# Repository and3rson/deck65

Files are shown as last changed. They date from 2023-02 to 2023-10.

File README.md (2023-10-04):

# Deck65

Homebrew 6502-based single-board computer with WiFi, built-in mechanical keyboard, uSD card adapter, I2C/SPI, EEPROM, & RTC.

Deck65 SBC
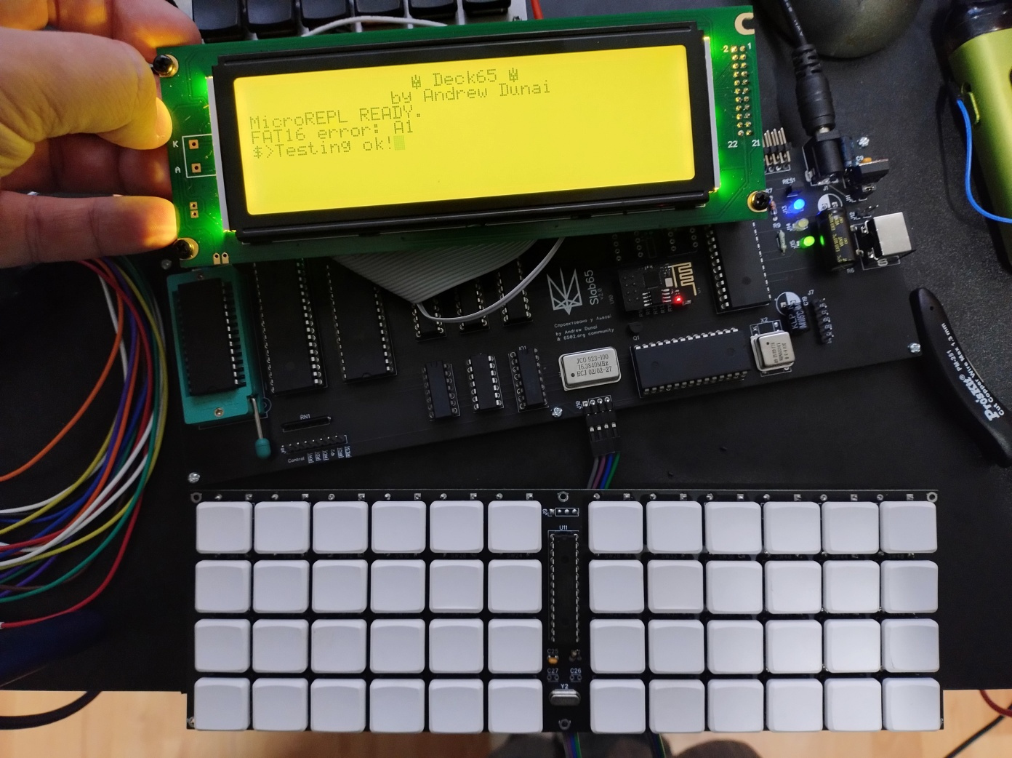
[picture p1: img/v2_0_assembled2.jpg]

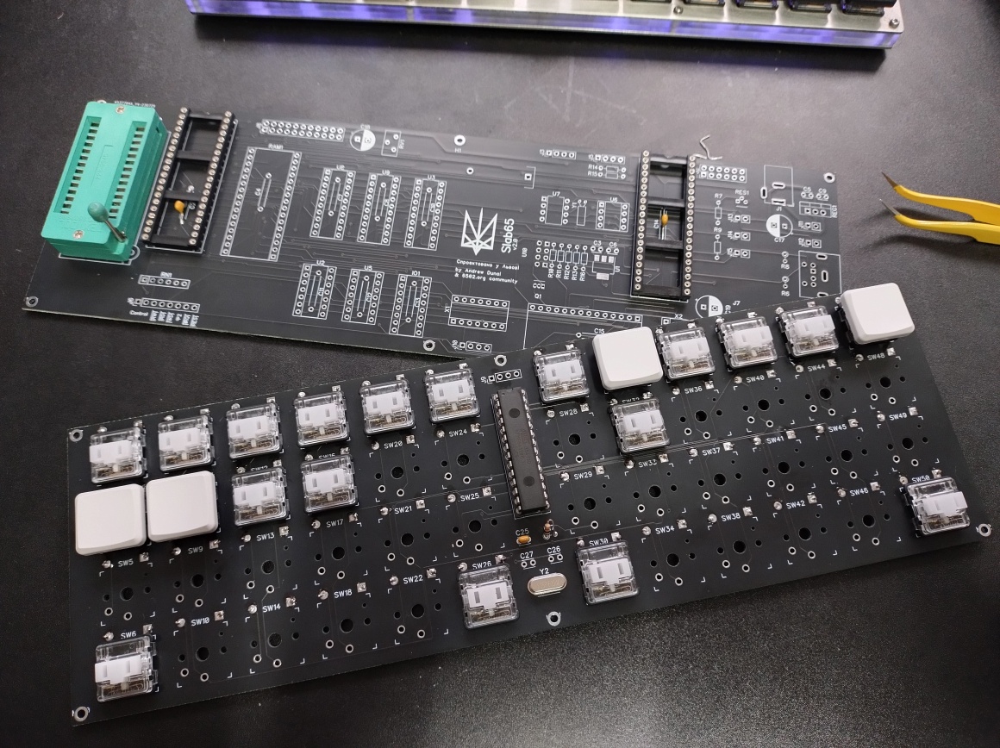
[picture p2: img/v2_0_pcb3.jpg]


- New discussion: <http://forum.6502.org/viewtopic.php?f=6&t=7682>
- Original thread (old SBC version): <http://forum.6502.org/viewtopic.php?f=12&t=7501>

Pull with `git pull --recurse-submodules`.

# Memory map

```
+--------------+-------+------------------+------+------------------------------------------+
| RANGE        | TYPE  | ADDR             | SIZE | Notes                                    |
+--------------+-------+------------------+------+------------------------------------------+
| $0000..$0FFF | RAM   | 0000------------ | 32 K | /EN = A15                                |
| $1000..$1FFF |       | 0001------------ |      | $0000..$1000 - zeropage & video buffer   |
| $2000..$2FFF |       | 0010------------ |      | $1000..$7FFF - programs from SD Card     |
| $3000..$3FFF |       | 0011------------ |      |                                          |
| $4000..$4FFF |       | 0100------------ |      |                                          |
| $5000..$5FFF |       | 0101------------ |      |                                          |
| $6000..$6FFF |       | 0110------------ |      |                                          |
| $7000..$7FFF |       | 0111------------ |      |                                          |
+--------------+-------+------------------+------+------------------------------------------+
| $8000..$8FFF | LOROM | 1000------------ | 16 K | /EN = NAND(A15, NAND(A14))               |
| $9000..$9FFF |       | 1001------------ |      | Contains OS ("MicroREPL")                |
| $A000..$AFFF |       | 1010------------ |      |                                          |
| $B000..$BFFF |       | 1011------------ |      |                                          |
+--------------+-------+------------------+------+------------------------------------------+
| $C000..$CFFF | N/C   | 1100------------ | 4 K  | Unused, may add extra '138 with /GA=/A13 |
+--------------+-------+------------------+------+------------------------------------------+
| $D000..$DFFF | I/O   | 1101------------ | 4 K  | G = A12, /GA = A13, /GB = NAND(A15, A14) |
|              |       | 1101-000-------- | 256B | $D000..$D0FF - RAM banking register      |
|              |       | 1101-001-------- | 256B | $D100..$D1FF - 6522 VIA                  |
|              |       | 1101-010-------- | 256B | $D200..$D2FF - 6551 ACIA                 |
|              |       | 1101-011-------- | 256B | $D300..$D3FF - T6963C LCD (240x64)       |
+--------------+-------+------------------+------+------------------------------------------+
| $E000..$EFFF | HIROM | 1110------------ | 8 K  | /EN = NAND(/NAND(A15, A14), A13)         |
| $F000..$FFFF |       | 1111------------ |      | Contains Kernel ("Kore")                 |
+--------------+-------+------------------+------+------------------------------------------+

LOROM (10xx) || HIROM (111x):
/EN = A15 && (/A14 || (A14 && A13))
/EN = NAND(A15, /A14 || /NAND(A14, A13))
/EN = NAND(A15, NAND(A14, NAND(A14, A13)))
```

# Features

- W65C02, 512 KB RAM (32KB visible to CPU, banked into 4 x 8 KB segments)
- 240x64 LCD display (T6963C)
- Built-in [mechanical PS/2 keyboard](./keyboard), powered by ATmega328P
- Internet! Works through ESP-01
- VIA W65C22<ins>N</ins>(6TPG-14)

  Provides:
  - SPI (used for Micro SD Card adapter)
  - I2C (used for RTC & EEPROM)
  - PS/2 host (used for built-in or external keyboard)
- ACIA W65C51<ins>N</ins>(6TPG-14)n

  Provides:
  - Communication with ESP-01
  - Communication with external devices through pin header
  > Note: I'm using NMOS-compatible versions of VIA & ACIA (<ins>N</ins> suffix) with open-drain /IRQ line.<br />
  > See http://archive.6502.org/datasheets/wdc_w65c22_sep_13_2010.pdf (page 25) for more details.
- Address decoder & underclocking - [ATF16V8B-15PU](./gal)
  > Main crystal is 16 MHz, and the CPU runs at either 8 MHz or 2 MHz.<br />
  > Reason for this is that T6963C LCD can only operate on up to 2.75 MHz.<br />
  > So when CPU needs to acccess the LCD, ATF16V8 divides clock speed by 4, bringing it down to 2 MHz.<br />
  > This is done by implementing a 2-bit counter using registered outputs.
- Memory banking: 74LS670
  > Entire RAM (first 32 KB) is divided into 4 x 8 KB segments.<br />
  > Each segment can use one of its own 16 banks.<br />
  > This allows to selectively bank parts of RAM in and out.<br />
  > Using a machine-tooled socket actually allows to connect JCO-8 or JCO-14 oscillators.
- Traco Power TSR 1-2450 (drop-in replacement for 7805)
  > It runs much cooler than L7805 since it's a switching regulator.<br />
  > I use them a lot, although they are not as cheap as 7805.

V2.0 schematic:
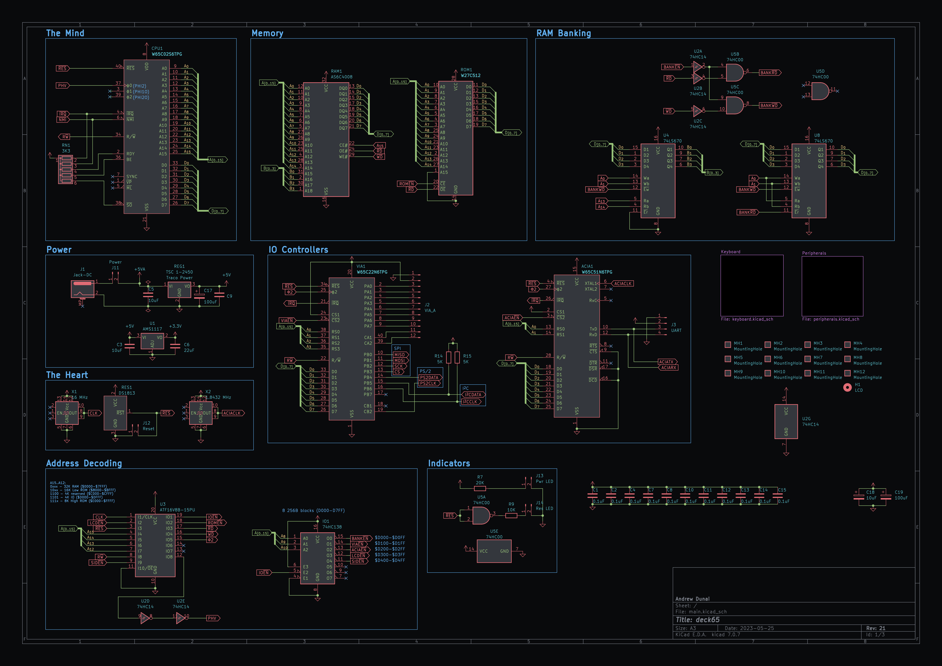
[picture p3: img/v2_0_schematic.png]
65c02s SBC PCB


# ROM

Kernel code currently provides the following features:
- Simple REPL shell to monitor memory & run programs
- 128x64 LCD (through VIA)
- PS/2 keyboard (through VIA)
- Micro SD Card in SPI mode (through VIA)
- I2C & SPI support
- Basic FAT16 support - listing root folder, loading/executing programs

# Resources

- [Kicad files](./kicad) - <https://www.kicad.org/>
- [DipTrace PCBs](./diptrace) - <https://diptrace.com/>
- [Circuits](./circuits) (created with [Digital](https://github.com/hneemann/Digital))
- [ROM sources](./rom) (written in 6502 Assembly, requires [cc65](https://cc65.github.io/) compiler)
- [SD Card programs](./sdcard) (written in 6502 C, requires [cc65](https://cc65.github.io/) compiler)
- [Keyboard firmware](./keyboard) (written in C)
- [GAL stuff](./gal) (hexadecimal 7-segment decoder, address decoder, etc using GAL16V8/GAL20V8, includes `galasm` as submodule)
- [Composite video test](./compvid) using ATtiny45 (requires [avra](https://github.com/Ro5bert/avra))

# So what can you do with it?

Playing snake, for example:

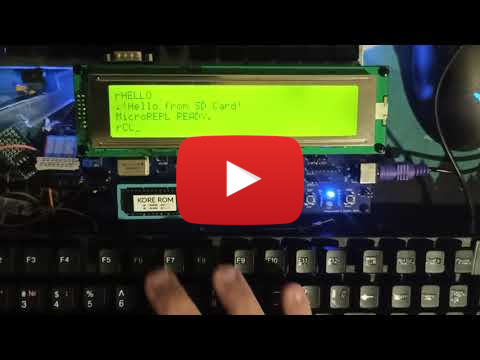
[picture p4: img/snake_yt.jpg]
Snake on 65C02 SBC (https://www.youtube.com/watch?v=boeysL1Isg4)


# Credits & references
- [6502.org community](forum.6502.org/) - Limitless help & support
- https://www.masswerk.at/6502/6502_instruction_set.html
- https://github.com/4x1md/kicad_libraries - Mini-DIN-6 symbol & footprint
- http://39k.ca/reading-files-from-fat16/
- https://laughtonelectronics.com/Arcana/KimKlone/Kimklone_opcode_mapping.html - cool illegal NOPs
- https://octopart.componentsearchengine.com/part.php?partID=570717&ref=octopart - Aries 28-526-10 footprint
- https://github.com/daprice/keyswitches.pretty - MX switches
- https://components101.com/sites/default/files/component_datasheet/Micro-SD-Card-Module-Datasheet.pdf - MicroSD card module datasheet & dimensions
- http://static.cactus.io/docs/sensors/temp-humidity/mcp9808/25095A.pdf - MCP9808 I2C temperature sensor
- https://ww1.microchip.com/downloads/aemDocuments/documents/MPD/ProductDocuments/DataSheets/24AA512-24LC512-24FC512-512K-Bit-I2C-Serial-EEPROM-20001754Q.pdf

# Links
- 6502 Primer: http://wilsonminesco.com/6502primer/
- Address Selector: https://circuitverse.org/simulator/embed/6502-address-selector
- Read-Write Selector: https://circuitverse.org/simulator/embed/6502-read-write-selector
- SID (HVSC) format: https://gist.github.com/cbmeeks/2b107f0a8d36fc461ebb056e94b2f4d6

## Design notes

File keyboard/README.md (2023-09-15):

# Keyboard

*- 48 keys is all you need.*

Firmware for ATmega328P-powered mechanical PS/2 keyboard.

Inspired by [QMK firmware](https://qmk.fm/).

## Features

- Key press delay & repeat
- Switch debouncing
- Basic & extended make/break scancodes
- Multi-layer support (extending total number of possible unique keys to thousands)

  I use two layer keys: "alpha" & "beta".
  - Main layer contains QWERTY layout and most used function keys (Ctrl/Alt/Shift/Meta, Return, Backspace, Escape, etc)
  - "Alpha" activates navigation layer (I/J/K/L = Up/Left/Down/Right, H/N = Home/End, U/O = PageUp/PageDown, etc)
  - "Beta" activates digits and F-keys.

## Keyboard layout

### Main layer
```
┏━━━━━┳━━━━━┯━━━━━┯━━━━━┯━━━━━┯━━━━━┳━━━━━┯━━━━━┯━━━━━┯━━━━━┯━━━━━┳━━━━━┓
┃ TAB ┃  Q  │  W  │  E  │  R  │  T  ┃  Y  │  U  │  I  │  O  │  P  ┃BKSPC┃
┣━━━━━╉─────┼─────┼─────┼─────┼─────╂─────┼─────┼─────┼─────┼─────╊━━━━━┫
┃  𝛼  ┃  A  │  S  │  D  │  F  │  G  ┃  H  │  J  │  K  │  L  │  ;  ┃ RET ┃
┣━━━━━╉─────┼─────┼─────┼─────┼─────╂─────┼─────┼─────┼─────┼─────╊━━━━━┫
┃SHIFT┃  Z  │  X  │  C  │  V  │  B  ┃  N  │  M  │  ,  │  .  │  /  ┃ CTRL┃
┣━━━━━╉─────┼─────┼─────┼─────┼─────╂─────┼─────┼─────┼─────┼─────╊━━━━━┫
┃ CTRL┃ ESC │     │     │     │SPACE┃SPACE│  𝛽  │     │     │     ┃     ┃
┗━━━━━┻━━━━━┷━━━━━┷━━━━━┷━━━━━┷━━━━━┻━━━━━┷━━━━━┷━━━━━┷━━━━━┷━━━━━┻━━━━━┛
```

### Alpha layer
```
┏━━━━━┳━━━━━┯━━━━━┯━━━━━┯━━━━━┯━━━━━┳━━━━━┯━━━━━┯━━━━━┯━━━━━┯━━━━━┳━━━━━┓
┃     ┃     │     │     │     │     ┃  -  │PAGE↑│  ↑  │PAGE↓│     ┃ DEL ┃
┣━━━━━╉─────┼─────┼─────┼─────┼─────╂─────┼─────┼─────┼─────┼─────╊━━━━━┫
┃     ┃     │     │     │     │     ┃ HOME│  ←  │  ↓  │  →  │  `  ┃     ┃
┣━━━━━╉─────┼─────┼─────┼─────┼─────╂─────┼─────┼─────┼─────┼─────╊━━━━━┫
┃     ┃     │     │     │     │     ┃ END │  =  │  [  │  ]  │     ┃     ┃
┣━━━━━╉─────┼─────┼─────┼─────┼─────╂─────┼─────┼─────┼─────┼─────╊━━━━━┫
┃     ┃     │     │     │     │     ┃     │     │     │     │     ┃     ┃
┗━━━━━┻━━━━━┷━━━━━┷━━━━━┷━━━━━┷━━━━━┻━━━━━┷━━━━━┷━━━━━┷━━━━━┷━━━━━┻━━━━━┛
```

### Beta layer
```
┏━━━━━┳━━━━━┯━━━━━┯━━━━━┯━━━━━┯━━━━━┳━━━━━┯━━━━━┯━━━━━┯━━━━━┯━━━━━┳━━━━━┓
┃     ┃  1  │  2  │  3  │  4  │  5  ┃  6  │  7  │  8  │  9  │  0  ┃ F12 ┃
┣━━━━━╉─────┼─────┼─────┼─────┼─────╂─────┼─────┼─────┼─────┼─────╊━━━━━┫
┃     ┃  F1 │  F2 │  F3 │  F4 │  F5 ┃  F6 │  F7 │  F8 │  F9 │ F10 ┃ F11 ┃
┣━━━━━╉─────┼─────┼─────┼─────┼─────╂─────┼─────┼─────┼─────┼─────╊━━━━━┫
┃     ┃     │     │     │     │     ┃     │     │     │     │     ┃     ┃
┣━━━━━╉─────┼─────┼─────┼─────┼─────╂─────┼─────┼─────┼─────┼─────╊━━━━━┫
┃     ┃     │     │     │     │     ┃     │     │     │     │     ┃     ┃
┗━━━━━┻━━━━━┷━━━━━┷━━━━━┷━━━━━┷━━━━━┻━━━━━┷━━━━━┷━━━━━┷━━━━━┷━━━━━┻━━━━━┛
```

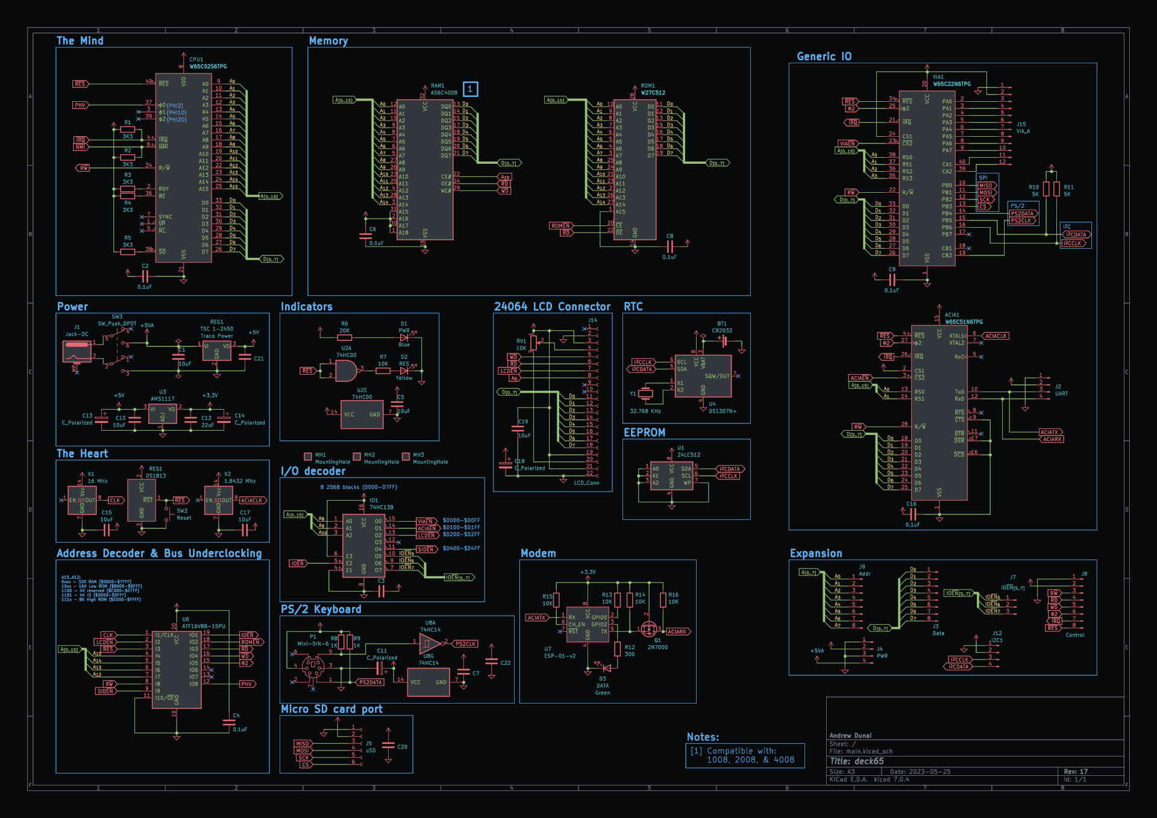
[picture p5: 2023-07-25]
img/v17_schematic.jpg

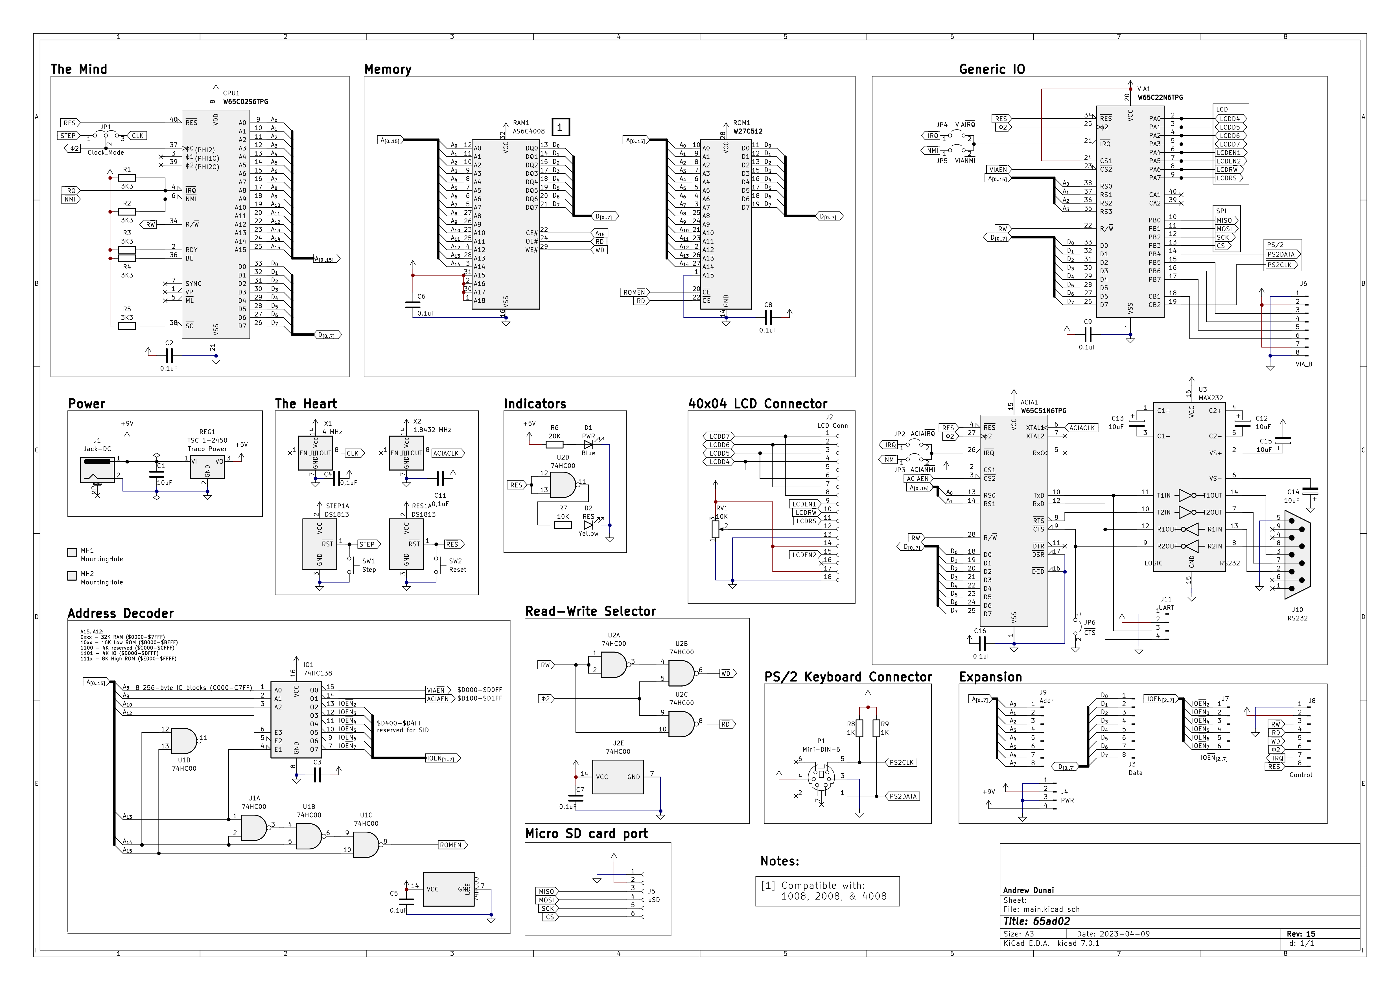
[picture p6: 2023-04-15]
img/v15_schematic.png

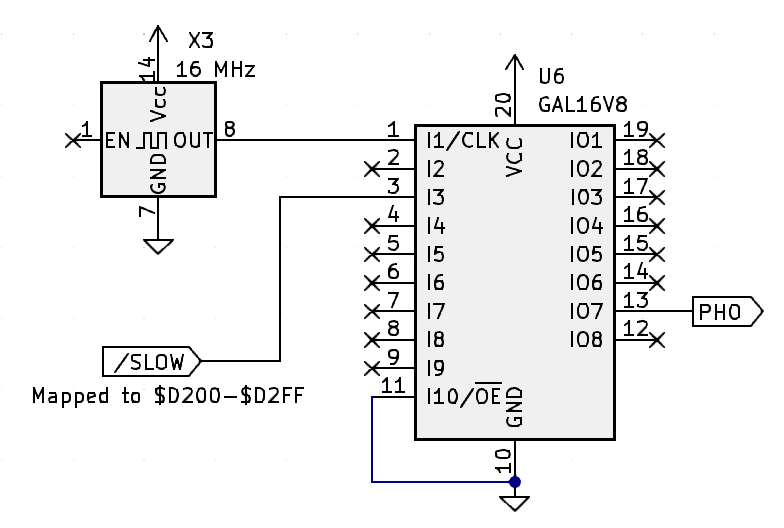
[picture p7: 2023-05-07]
img/slowbus_schematic.png

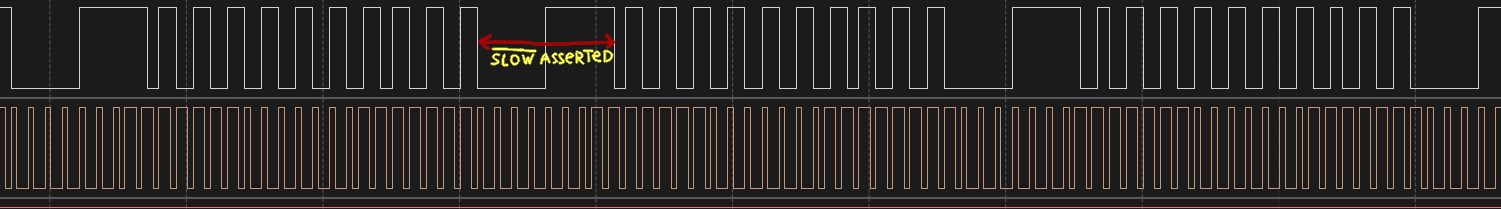
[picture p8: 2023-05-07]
img/slowbus_real.png

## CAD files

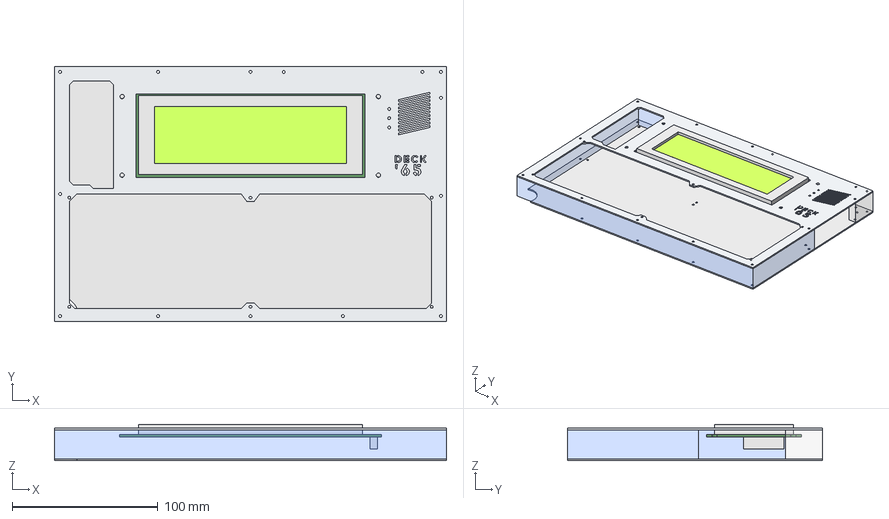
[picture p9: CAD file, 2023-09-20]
case/main_case.FCStd
269.2 x 175.3 x 25.0 mm
Тіло
Тіло001
Тіло002
Тіло003
PCBBody
ConnBody
Matrix
Display

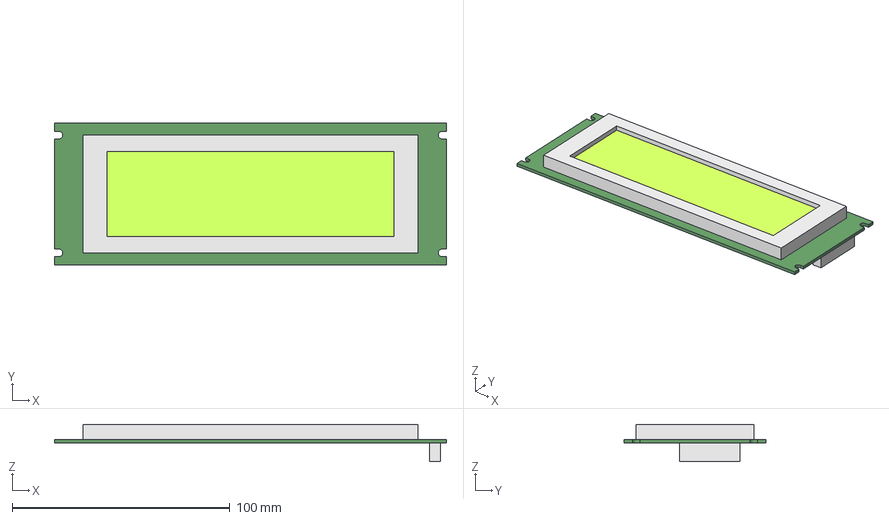
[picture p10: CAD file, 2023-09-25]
case/lcd.FCStd
180.0 x 65.0 x 17.1 mm
PCBBody
ConnBody
Matrix
Display

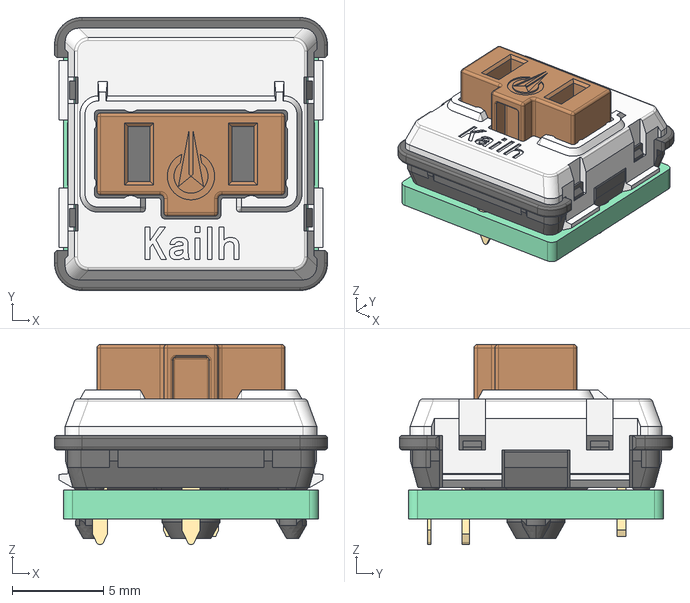
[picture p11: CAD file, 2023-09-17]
kicad/3dmodels/Kailh Choc Low Profile Switch.step
15.0 x 15.0 x 11.0 mm

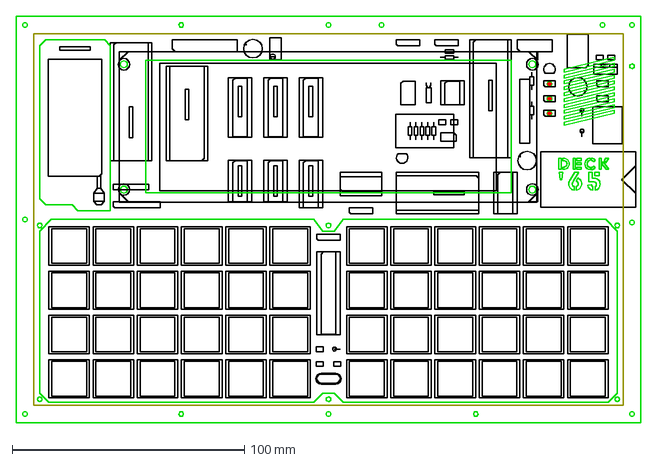
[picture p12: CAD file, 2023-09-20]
case/top.dxf
269.2 x 175.3 mm

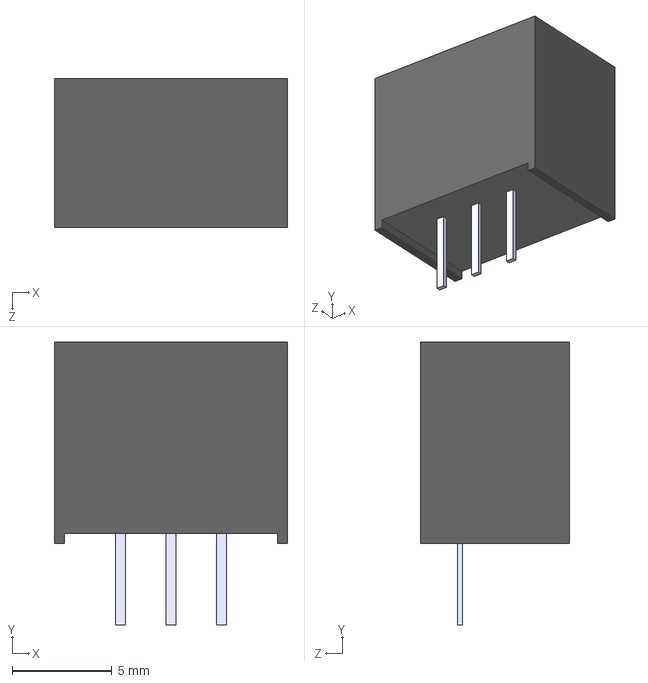
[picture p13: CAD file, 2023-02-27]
kicad/3dmodels/TSR_1-2450.stp
11.7 x 14.2 x 7.50 mm

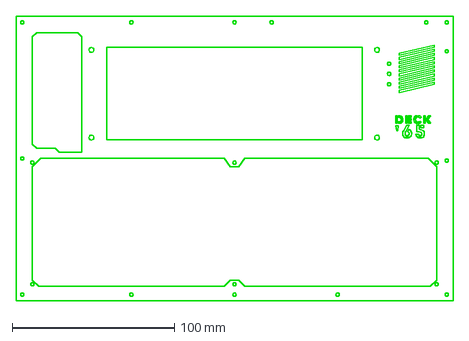
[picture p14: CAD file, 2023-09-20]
case/top_print.dxf
269.2 x 175.3 mm

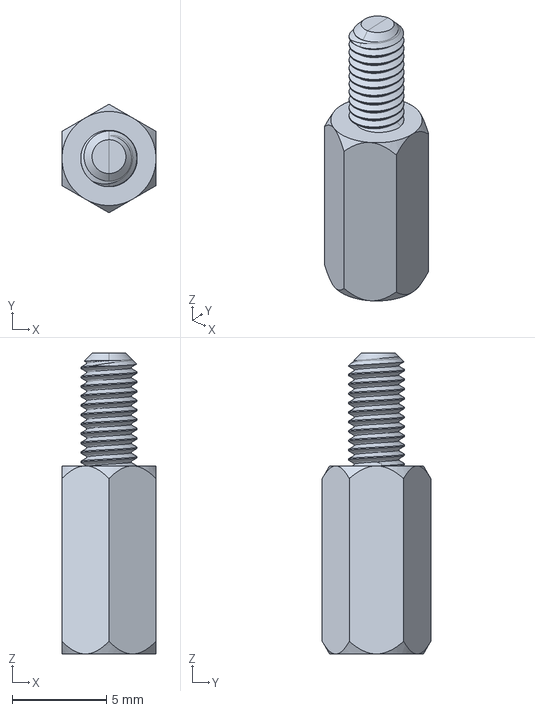
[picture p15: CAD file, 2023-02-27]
kicad/3dmodels/Hex_Spacer_MF_M3_L10mm.stp
5.00 x 5.77 x 16.0 mm

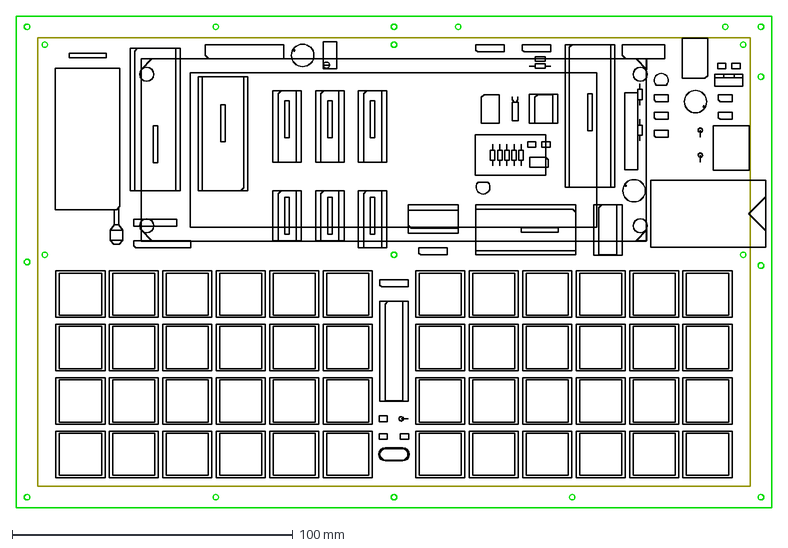
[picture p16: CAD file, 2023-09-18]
case/bottom.dxf
269.2 x 175.3 mm

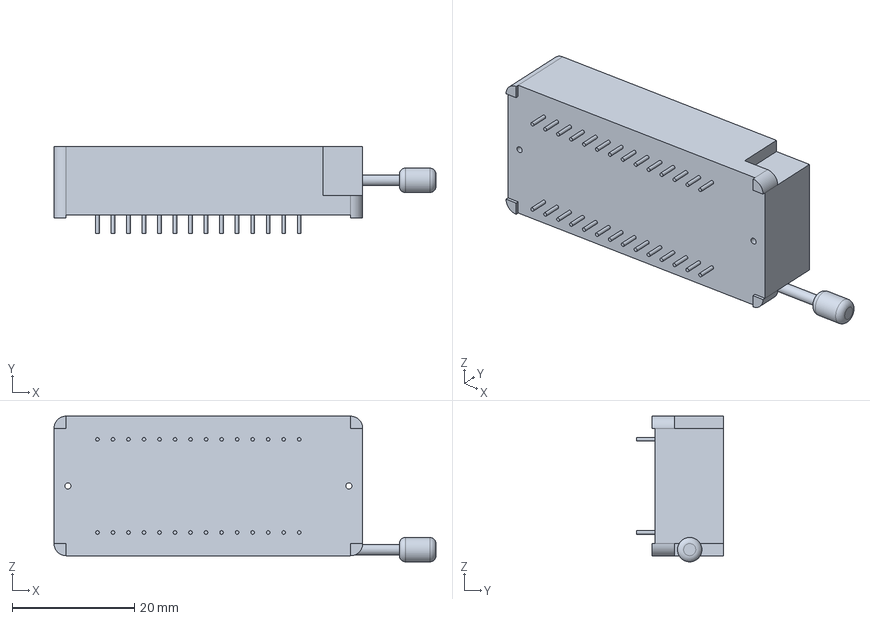
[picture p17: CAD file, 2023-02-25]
kicad/3dmodels/28ZIF_PlaceHolderRevB.stp
62.5 x 14.2 x 23.9 mm

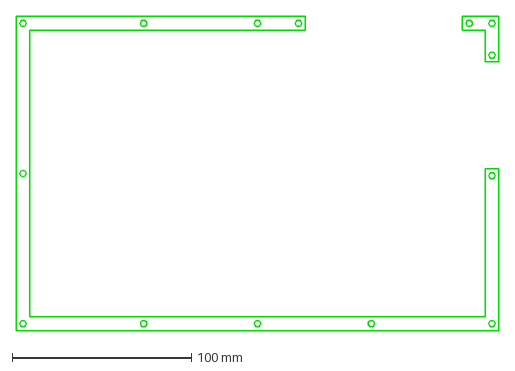
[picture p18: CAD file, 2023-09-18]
case/middle.dxf
269.2 x 175.3 mm

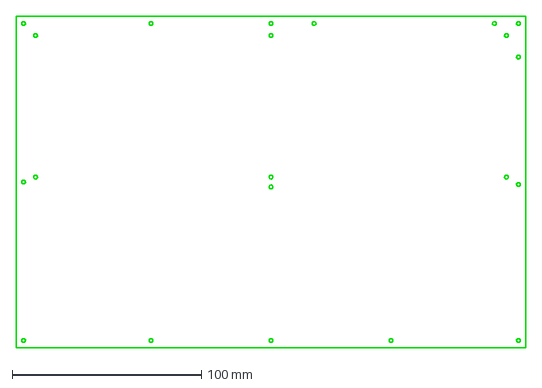
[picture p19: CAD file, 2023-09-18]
case/bottom_print.dxf
269.2 x 175.3 mm

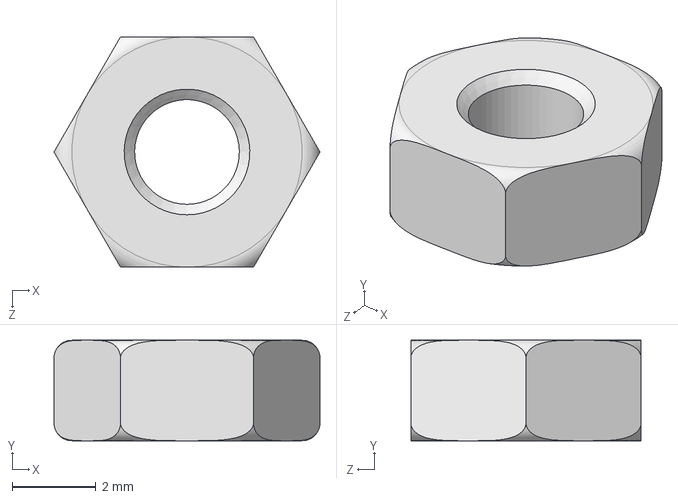
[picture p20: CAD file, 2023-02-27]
kicad/3dmodels/DIN_934_Nut_M3.stp
6.35 x 2.40 x 5.50 mm

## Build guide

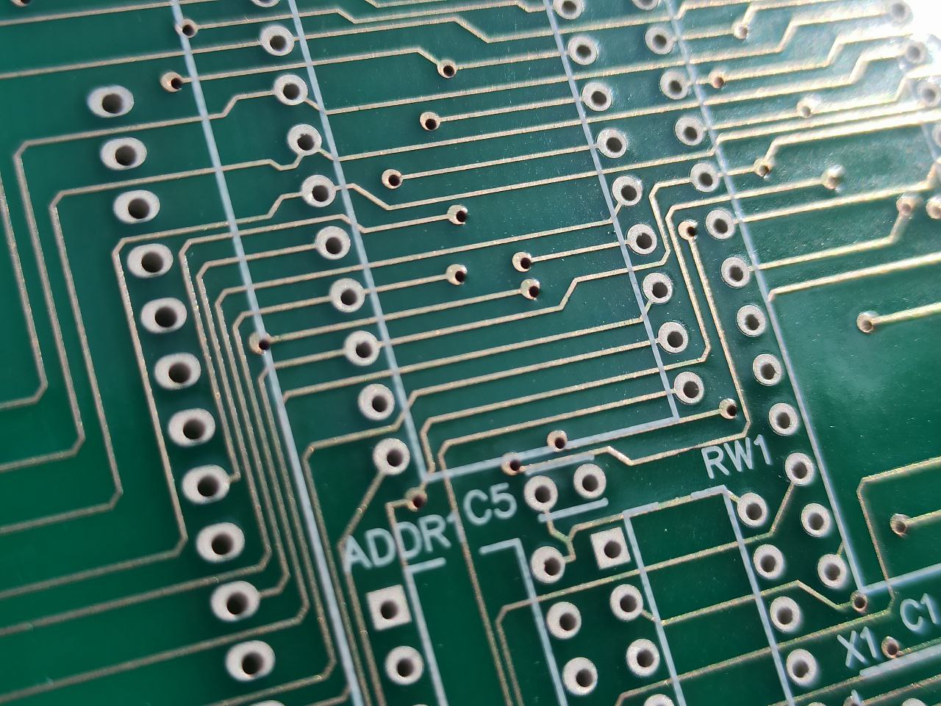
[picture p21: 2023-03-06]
img/v09_printed2.jpg

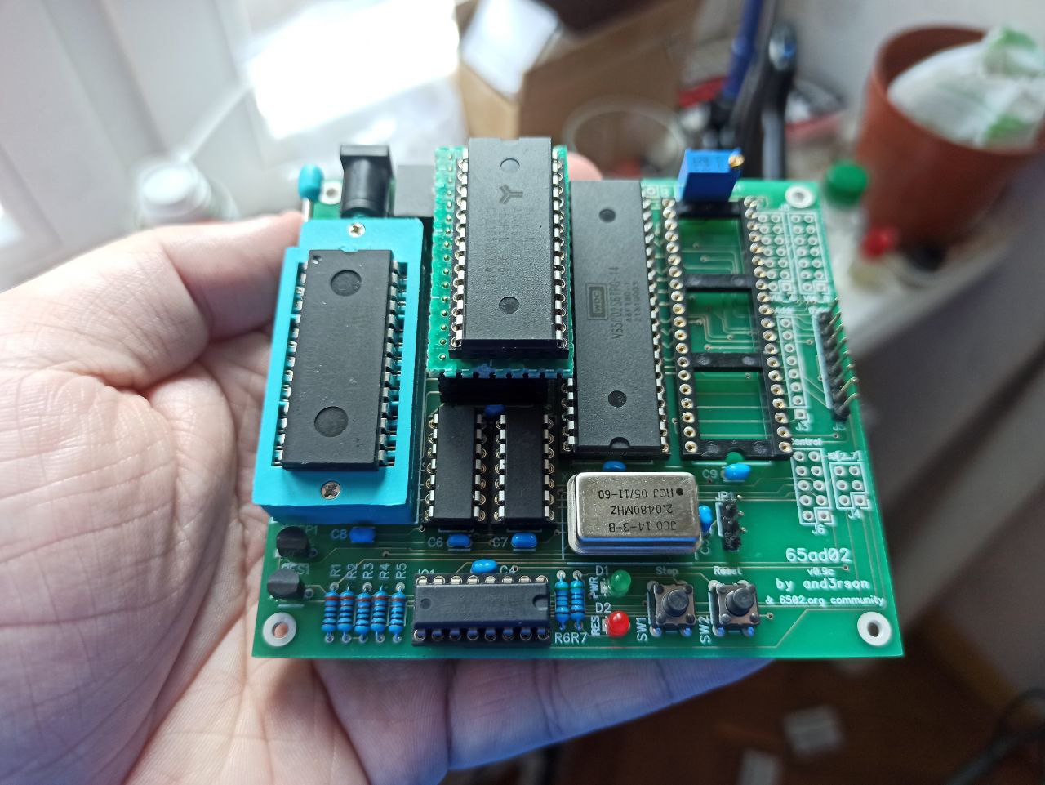
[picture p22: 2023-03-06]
img/v09_printed3.jpg

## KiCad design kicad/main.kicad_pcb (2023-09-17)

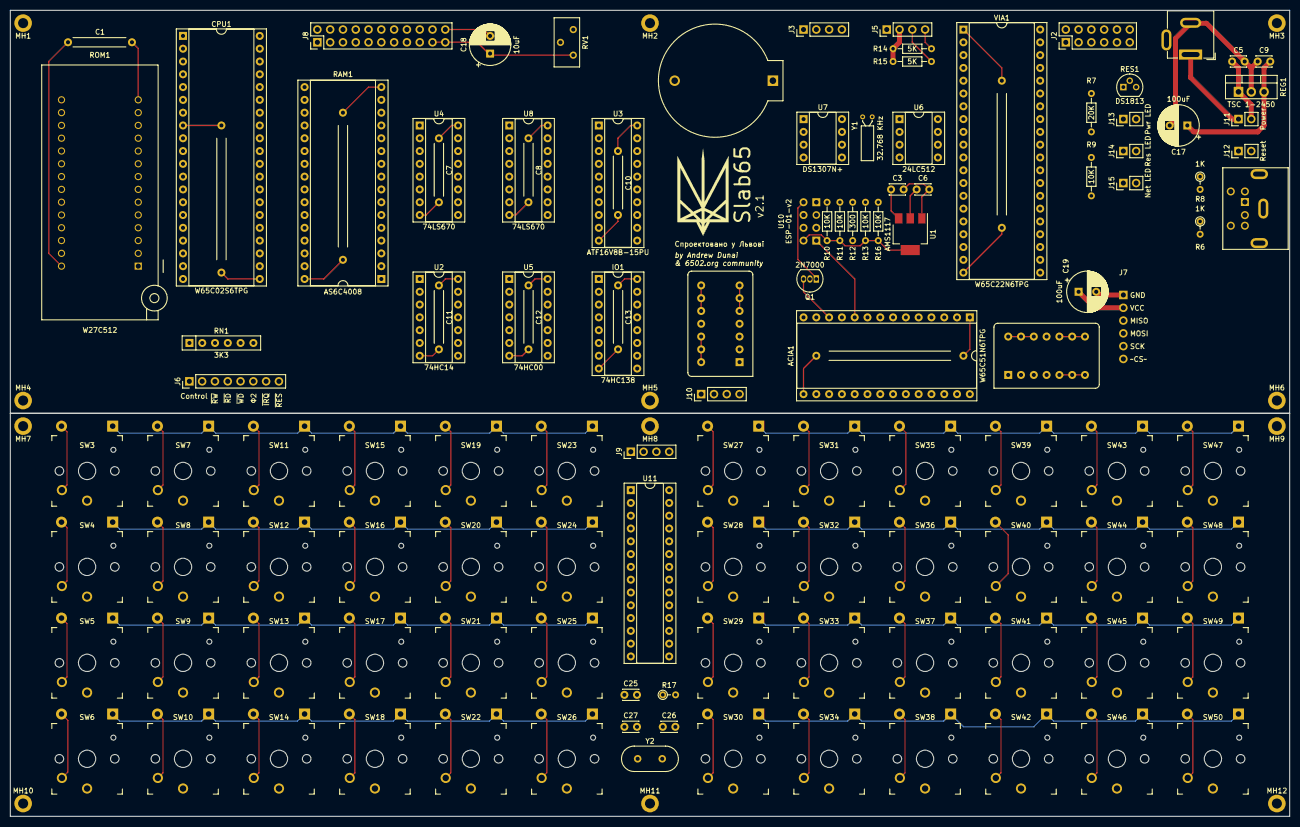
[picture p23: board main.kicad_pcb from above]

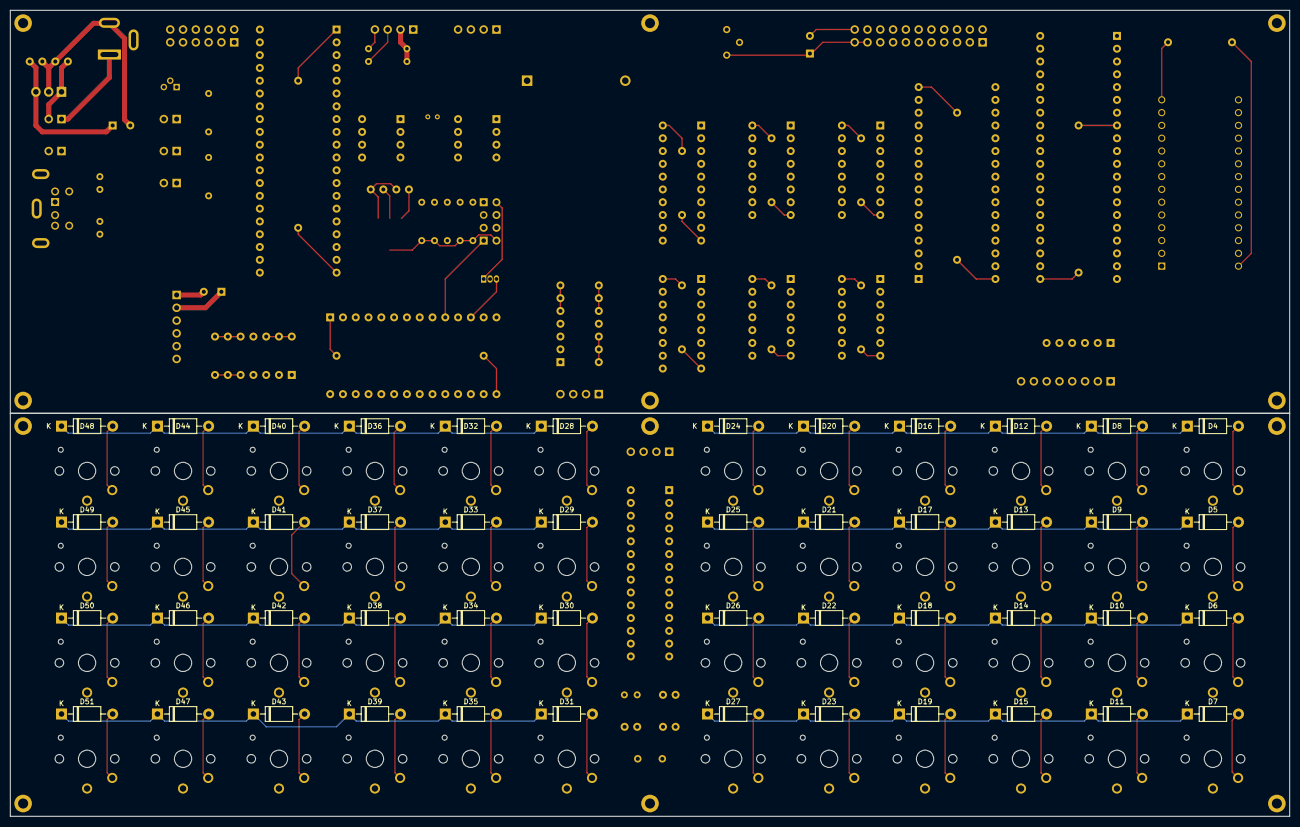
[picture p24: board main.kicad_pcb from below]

Board: 2 copper layers, 254.0 x 160.0 mm, 183 parts (48 on the bottom side), 164 nets.

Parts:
ACIA1: W65C51N6TPG; DIP-28_W15.24mm_Socket
BT1: CR2032; BatteryHolder_CR2032
C1, C7, C8, C10, C11, C12, C13: 0.1uF; C_Disc_Long
C2, C4, C14, C15: 0.1uF; C_Disc_VeryLong
C3, C5: 10uF; C_Disc_D3.0mm_W2.0mm_P2.50mm
C6: 22uF; C_Disc_D3.0mm_W2.0mm_P2.50mm
C9: 0.1uF; C_Disc_D3.0mm_W2.0mm_P2.50mm
C17, C19: 100uF; CP_Radial_D8.0mm_P3.50mm
C18: 10uF; CP_Radial_D8.0mm_P3.50mm
C25: 0,1uF; C_Disc_D3.0mm_W2.0mm_P2.50mm
C26, C27: 22pF; C_Disc_D3.0mm_W2.0mm_P2.50mm
CPU1: W65C02S6TPG; DIP-40_W15.24mm_Socket
D4, D5, D6, D7, D8, D9, D10, D11, D12, D13, D14, D15, D16, D17, D18, D19, D20, D21, D22, D23, D24, D25, D26, D27, D28, D29, D30, D31, D32, D33, D34, D35, D36, D37, D38, D39, D40, D41, D42, D43, D44, D45, D46, D47, D48, D49, D50, D51: 1N4001; D_DO-41_SOD81_P10.16mm_Horizontal
H1: LCD; LCD24064_silk
IO1: 74HC138; DIP-16_W7.62mm_Socket
J1: Jack-DC; BarrelJackEdge
J2: VIA_A; PinHeader_2x06_P2.54mm_Vertical
J3: UART; PinHeader_1x04_P2.54mm_Vertical
J5: I2C1; PinHeader_1x04_P2.54mm_Vertical
J6: Control; PinHeader_1x08_P2.54mm_Vertical
J7: uSD; MicroSD-Adapter
J8: LCD_Conn; PinHeader_2x11_P2.54mm_Vertical
J9, J10: Keyboard; PinHeader_1x04_P2.54mm_Vertical
J11: Power; PinHeader_1x02_P2.54mm_Vertical
J12: Reset; PinHeader_1x02_P2.54mm_Vertical
J13: Pwr LED; PinHeader_1x02_P2.54mm_Vertical
J14: Res LED; PinHeader_1x02_P2.54mm_Vertical
J15: Net LED; PinHeader_1x02_P2.54mm_Vertical
MH1, MH2, MH3, MH4, MH5, MH6, MH7, MH8, MH9, MH10, MH11, MH12: MountingHole; Hole_2x3.5
P1: Mini-DIN-6; Connector_Mini-DIN_Female_6Pin_2rows
Q1: 2N7000; TO-92_Inline
R6, R8: 1K; R_Axial_DIN0204_L3.6mm_D1.6mm_P2.54mm_Vertical
R7: 20K; R_Axial_DIN0204_L3.6mm_D1.6mm_P7.62mm_Horizontal
R9, R10, R11, R13, R16: 10K; R_Axial_DIN0204_L3.6mm_D1.6mm_P7.62mm_Horizontal
R12: 300; R_Axial_DIN0204_L3.6mm_D1.6mm_P7.62mm_Horizontal
R14, R15: 5K; R_Axial_DIN0204_L3.6mm_D1.6mm_P7.62mm_Horizontal
R17: 5K; R_Axial_DIN0204_L3.6mm_D1.6mm_P2.54mm_Vertical
RAM1: AS6C4008; DIP-32_W15.24mm_Socket
REG1: TSC 1-2450; TO-220-3_Vertical
RES1: DS1813; TO-92
RN1: 3K3; R_Array_SIP6
ROM1: W27C512; ZIF28
RV1: 10K; Potentiometer_Bourns_3296Y_Vertical
SW3, SW4, SW5, SW6, SW7, SW8, SW9, SW10, SW11, SW12, SW13, SW14, SW15, SW16, SW17, SW18, SW19, SW20, SW21, SW22, SW23, SW24, SW25, SW26, SW27, SW28, SW29, SW30, SW31, SW32, SW33, SW34, SW35, SW36, SW37, SW38, SW39, SW40, SW41, SW42, SW43, SW44, SW45, SW46, SW47, SW48, SW49, SW50: SW_Push; SW_PG1350
U1: AMS1117; SOT-223-3_TabPin2
U2: 74HC14; DIP-14_W7.62mm_Socket
U3: ATF16V8B-15PU; DIP-20_W7.62mm_Socket
U4, U8: 74LS670; DIP-16_W7.62mm_Socket
U5: 74HC00; DIP-14_W7.62mm_Socket
U6: 24LC512; DIP-8_W7.62mm_Socket
U7: DS1307N+; DIP-8_W7.62mm_Socket
U10: ESP-01-v2; ESP-01
U11: ATmega328-P; DIP-28_W7.62mm_Socket
VIA1: W65C22N6TPG; DIP-40_W15.24mm_Socket
X1: 16 MHz; Oscillator_DIP-8-14
X2: 1.8432 MHz; Oscillator_DIP-8-14
Y1: 32.768 KHz; Crystal_C26-LF_D2.1mm_L6.5mm_Horizontal
Y2: Crystal; Crystal_HC49-U_Vertical

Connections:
+3.3V: C6.1, Q1.2 (G), R10.2, R11.2, R13.2, R16.2, U1.2 (VO), U10.8 (VCC)
+5V: ACIA1.2 (CS1), ACIA1.15 (VCC), C1.1, C2.1, C3.1, C4.1, C7.1, C8.1, C9.2, C10.1, C11.1, C12.1, C13.1, C14.1, C15.1, C17.1, C18.1, C19.1, CPU1.8 (VDD), IO1.6 (E3), IO1.16 (VCC), J2.2, J3.2, J5.2, J6.2, J7.2, J8.3, J8.19, J8.21, J10.2, P1.4, R6.2, R7.1, R8.2, R14.2, R15.2, RAM1.32 (VCC), REG1.3 (VO), RES1.2 (VCC), RN1.1 (common), ROM1.28 (VCC), RV1.1, U1.3 (VI), U2.14 (VCC), U3.20 (VCC), U4.16 (VCC), U5.14 (VCC), U6.8 (VCC), U7.8 (VCC), U8.16 (VCC), VIA1.20 (VCC), VIA1.24 (CS1), X1.12, X1.13, X1.14 (Vcc), X2.12, X2.13, X2.14 (Vcc)
+5VA: C5.1, J11.2, REG1.1 (VI)
ACIACLK: ACIA1.6 (XTAL1), X2.8 (OUT), X2.9, X2.10
ACIARX: ACIA1.12 (RxD), J3.4, Q1.3 (D), R16.1
ACIATX: ACIA1.10 (TxD), J3.3, U10.1 (RX)
ACIA~EN: ACIA1.3 (~CS2), IO1.13 (O2)
A_{0}: ACIA1.13 (RS0), CPU1.9 (A0), J8.8, RAM1.12 (A0), ROM1.10 (A0), U4.14 (Wa), U8.5 (Ra), U8.14 (Wa), VIA1.38 (RS0)
A_{1}: ACIA1.14 (RS1), CPU1.10 (A1), RAM1.11 (A1), ROM1.9 (A1), U4.13 (Wb), U8.4 (Rb), U8.13 (Wb), VIA1.37 (RS1)
A_{2}: CPU1.11 (A2), RAM1.10 (A2), ROM1.8 (A2), VIA1.36 (RS2)
A_{3}: CPU1.12 (A3), RAM1.9 (A3), ROM1.7 (A3), VIA1.35 (RS3)
A_{4}: CPU1.13 (A4), RAM1.8 (A4), ROM1.6 (A4)
A_{5}: CPU1.14 (A5), RAM1.7 (A5), ROM1.5 (A5)
A_{6}: CPU1.15 (A6), RAM1.6 (A6), ROM1.4 (A6)
A_{7}: CPU1.16 (A7), RAM1.5 (A7), ROM1.3 (A7)
A_{8}: CPU1.17 (A8), IO1.1 (A0), RAM1.27 (A8), ROM1.25 (A8)
A_{9}: CPU1.18 (A9), IO1.2 (A1), RAM1.26 (A9), ROM1.24 (A9)
A_{10}: CPU1.19 (A10), IO1.3 (A2), RAM1.23 (A10), ROM1.21 (A10)
A_{11}: CPU1.20 (A11), RAM1.25 (A11), ROM1.23 (A11)
A_{12}: CPU1.22 (A12), RAM1.4 (A12), ROM1.2 (A12), U3.7 (I7)
A_{13}: CPU1.23 (A13), RAM1.28 (A13), ROM1.26 (A13), U3.6 (I6), U4.5 (Ra)
A_{14}: CPU1.24 (A14), RAM1.3 (A14), ROM1.27 (A14), U3.5 (I5), U4.4 (Rb)
A_{15}: CPU1.25 (A15), RAM1.22 (CE#), U3.4 (I4)
BANK~EN: IO1.15 (O0), U2.1
BANK~RD: U5.6, U8.11 (~Er)
BANK~WD: U4.12 (~Ew), U5.8, U8.12 (~Ew)
B_{0}: RAM1.31 (A15), U4.10 (Q1)
B_{1}: RAM1.2 (A16), U4.9 (Q2)
B_{2}: RAM1.30 (A17), U4.7 (Q3)
B_{3}: RAM1.1 (A18), U4.6 (Q4)
CLK: U3.1 (I1/CLK), X1.8 (OUT), X1.9, X1.10
COL1: SW3.1, SW4.1, SW5.1, SW6.1, SW27.1, SW28.1, SW29.1, SW30.1, U11.14 (PB0)
COL2: SW7.1, SW8.1, SW9.1, SW10.1, SW31.1, SW32.1, SW33.1, SW34.1, U11.15 (PB1)
COL3: SW11.1, SW12.1, SW13.1, SW14.1, SW35.1, SW36.1, SW37.1, SW38.1, U11.16 (PB2)
COL4: SW15.1, SW16.1, SW17.1, SW18.1, SW39.1, SW40.1, SW41.1, SW42.1, U11.17 (PB3)
COL5: SW19.1, SW20.1, SW21.1, SW22.1, SW43.1, SW44.1, SW45.1, SW46.1, U11.18 (PB4)
COL6: SW23.1, SW24.1, SW25.1, SW26.1, SW47.1, SW48.1, SW49.1, SW50.1, U11.19 (PB5)
CS: J7.6, VIA1.13 (PB3)
D_{0}: ACIA1.18 (D0), CPU1.33 (D0), J8.11, RAM1.13 (DQ0), ROM1.11 (D0), U4.15 (D1), U8.10 (Q1), U8.15 (D1), VIA1.33 (D0)
D_{1}: ACIA1.19 (D1), CPU1.32 (D1), J8.12, RAM1.14 (DQ1), ROM1.12 (D1), U4.1 (D2), U8.1 (D2), U8.9 (Q2), VIA1.32 (D1)
D_{2}: ACIA1.20 (D2), CPU1.31 (D2), J8.13, RAM1.15 (DQ2), ROM1.13 (D2), U4.2 (D3), U8.2 (D3), U8.7 (Q3), VIA1.31 (D2)
D_{3}: ACIA1.21 (D3), CPU1.30 (D3), J8.14, RAM1.17 (DQ3), ROM1.15 (D3), U4.3 (D4), U8.3 (D4), U8.6 (Q4), VIA1.30 (D3)
D_{4}: ACIA1.22 (D4), CPU1.29 (D4), J8.15, RAM1.18 (DQ4), ROM1.16 (D4), VIA1.29 (D4)
D_{5}: ACIA1.23 (D5), CPU1.28 (D5), J8.16, RAM1.19 (DQ5), ROM1.17 (D5), VIA1.28 (D5)
D_{6}: ACIA1.24 (D6), CPU1.27 (D6), J8.17, RAM1.20 (DQ6), ROM1.18 (D6), VIA1.27 (D6)
D_{7}: ACIA1.25 (D7), CPU1.26 (D7), J8.18, RAM1.21 (DQ7), ROM1.19 (D7), VIA1.26 (D7)
GND: ACIA1.1 (VSS), ACIA1.9 (~CTS), ACIA1.16 (~DCD), ACIA1.17 (~DSR), BT1.2 (-), C1.2, C2.2, C3.2, C4.2, C5.2, C6.2, C7.2, C8.2, C9.1, C10.2, C11.2, C12.2, C13.2, C14.2, C15.2, C17.2, C18.2, C19.2, CPU1.21 (VSS), IO1.4 (E1), IO1.8 (GND), J1.2, J2.1, J3.1, J5.1, J6.1, J7.1, J8.2, J8.22, J10.1, J12.1, J13.2, J14.2, J15.2, P1.3, RAM1.16 (VSS), REG1.2 (GND), RES1.3 (GND), ROM1.1 (A15), ROM1.14 (GND), U1.1 (ADJ), U2.7 (GND), U3.10 (GND), U3.11 (I10/~OE), U4.8 (GND), U4.11 (~Er), U5.7 (GND), U6.1 (A0), U6.2 (A1), U6.3 (A2), U6.4 (GND), U6.7 (WP), U7.4 (GND), U8.8 (GND), U10.4 (GND), VIA1.1 (VSS), X1.5, X1.6, X1.7 (GND), X2.5, X2.6, X2.7 (GND)
IO~EN: IO1.5 (E2), U3.19 (IO1)
I^{2}CCLK: J5.3, R15.1, U6.6 (SCL), U7.6 (SCL), VIA1.16 (PB6)
I^{2}CDATA: J5.4, R14.1, U6.5 (SDA), U7.5 (SDA), VIA1.15 (PB5)
LCD~EN: IO1.12 (O3), J8.7, U3.2 (I2)
MISO: J7.3, VIA1.10 (PB0)
MOSI: J7.4, VIA1.11 (PB1)
unnamed: BT1.1 (+), U7.3 (VBAT)
unnamed: CPU1.36 (BE), RN1.5 (R4)
unnamed: CPU1.2 (RDY), RN1.4 (R3)
unnamed: CPU1.38 (~SO), RN1.6 (R5)
unnamed: D4.2 (A), SW3.2
unnamed: D5.2 (A), SW4.2
unnamed: D6.2 (A), SW5.2
unnamed: D7.2 (A), SW6.2
unnamed: D8.2 (A), SW7.2
unnamed: D9.2 (A), SW8.2
unnamed: D10.2 (A), SW9.2
unnamed: D11.2 (A), SW10.2
unnamed: D12.2 (A), SW11.2
unnamed: D13.2 (A), SW12.2
unnamed: D14.2 (A), SW13.2
unnamed: D15.2 (A), SW14.2
unnamed: D16.2 (A), SW15.2
unnamed: D17.2 (A), SW16.2
unnamed: D18.2 (A), SW17.2
unnamed: D19.2 (A), SW18.2
unnamed: D20.2 (A), SW19.2
unnamed: D21.2 (A), SW20.2
unnamed: D22.2 (A), SW21.2
unnamed: D23.2 (A), SW22.2
unnamed: D24.2 (A), SW23.2
unnamed: D25.2 (A), SW24.2
unnamed: D26.2 (A), SW25.2
unnamed: D27.2 (A), SW26.2
unnamed: D28.2 (A), SW27.2
unnamed: D29.2 (A), SW28.2
unnamed: D30.2 (A), SW29.2
unnamed: D31.2 (A), SW30.2
unnamed: D32.2 (A), SW31.2
unnamed: D33.2 (A), SW32.2
unnamed: D34.2 (A), SW33.2
unnamed: D35.2 (A), SW34.2
unnamed: D36.2 (A), SW35.2
unnamed: D37.2 (A), SW36.2
unnamed: D38.2 (A), SW37.2
unnamed: D39.2 (A), SW38.2
unnamed: D40.2 (A), SW39.2
unnamed: D41.2 (A), SW40.2
unnamed: D42.2 (A), SW41.2
unnamed: D43.2 (A), SW42.2
unnamed: D44.2 (A), SW43.2
unnamed: D45.2 (A), SW44.2
unnamed: D46.2 (A), SW45.2
unnamed: D47.2 (A), SW46.2
unnamed: D48.2 (A), SW47.2
unnamed: D49.2 (A), SW48.2
unnamed: D50.2 (A), SW49.2
unnamed: D51.2 (A), SW50.2
unnamed: J2.3, VIA1.2 (PA0)
unnamed: J2.4, VIA1.3 (PA1)
unnamed: J2.5, VIA1.4 (PA2)
unnamed: J2.6, VIA1.5 (PA3)
unnamed: J2.7, VIA1.6 (PA4)
unnamed: J2.8, VIA1.7 (PA5)
unnamed: J2.9, VIA1.8 (PA6)
unnamed: J2.10, VIA1.9 (PA7)
unnamed: J2.11, VIA1.40 (CA1)
unnamed: J2.12, VIA1.39 (CA2)
unnamed: J8.4, RV1.2
unnamed: J8.20, RV1.3
unnamed: C25.1, C26.1, C27.1, J9.1, U11.8 (GND), U11.22 (GND)
unnamed: J9.2, R17.2, U11.7 (VCC), U11.20 (AVCC)
unnamed: J9.3, U11.12 (PD6)
unnamed: J9.4, U11.13 (PD7)
unnamed: J1.1, J11.1
unnamed: J13.1, R7.2
unnamed: J14.1, R9.2
unnamed: J15.1, R12.1
unnamed: P1.5, R6.1, U2.13
unnamed: Q1.1 (S), R13.1, U10.5 (TX)
unnamed: R9.1, U5.3
unnamed: U2.2, U5.4, U5.9
unnamed: U2.4, U5.5
unnamed: U2.6, U5.10
unnamed: U2.8, U2.11
unnamed: U2.9, U3.12 (IO8)
unnamed: U7.1 (X1), Y1.1
unnamed: U7.2 (X2), Y1.2
unnamed: R10.1, U10.6 (CH_EN)
unnamed: R11.1, U10.2 (GPIO0)
unnamed: R12.2, U10.3 (GPIO2)
unnamed: C25.2, U11.21 (AREF)
unnamed: C26.2, U11.9 (XTAL1/PB6), Y2.2
unnamed: C27.2, U11.10 (XTAL2/PB7), Y2.1
unnamed: R17.1, U11.1 (~RESET/PC6)
PHV: CPU1.37 (ϕ0), U2.10
PS2CLK: J10.3, U2.12, VIA1.19 (CB2)
PS2DATA: J10.4, P1.1, R8.1, VIA1.14 (PB4)
ROM~EN: ROM1.20 (~CE), U3.18 (IO2)
ROW1: D4.1 (K), D8.1 (K), D12.1 (K), D16.1 (K), D20.1 (K), D24.1 (K), U11.2 (PD0)
ROW2: D5.1 (K), D9.1 (K), D13.1 (K), D17.1 (K), D21.1 (K), D25.1 (K), U11.3 (PD1)
ROW3: D6.1 (K), D10.1 (K), D14.1 (K), D18.1 (K), D22.1 (K), D26.1 (K), U11.4 (PD2)
ROW4: D7.1 (K), D11.1 (K), D15.1 (K), D19.1 (K), D23.1 (K), D27.1 (K), U11.5 (PD3)
ROW5: D28.1 (K), D32.1 (K), D36.1 (K), D40.1 (K), D44.1 (K), D48.1 (K), U11.27 (PC4)
ROW6: D29.1 (K), D33.1 (K), D37.1 (K), D41.1 (K), D45.1 (K), D49.1 (K), U11.26 (PC3)
ROW7: D30.1 (K), D34.1 (K), D38.1 (K), D42.1 (K), D46.1 (K), D50.1 (K), U11.25 (PC2)
ROW8: D31.1 (K), D35.1 (K), D39.1 (K), D43.1 (K), D47.1 (K), D51.1 (K), U11.24 (PC1)
R~W: ACIA1.28 (R/~W), CPU1.34 (R/~W), J6.3, U3.8 (I8), VIA1.22 (R/~W)
SCK: J7.5, VIA1.12 (PB2)
SID~EN: IO1.11 (O4), U3.9 (I9)
VIA~EN: IO1.14 (O1), VIA1.23 (~CS2)
~IRQ: ACIA1.26 (~IRQ), CPU1.4 (~IRQ), J6.7, RN1.2 (R1), VIA1.21 (~IRQ)
~NMI: CPU1.6 (~NMI), RN1.3 (R2)
~RD: J6.4, J8.6, RAM1.24 (OE#), ROM1.22 (~OE), U2.3, U3.17 (I03)
~RES: ACIA1.4 (~RES), CPU1.40 (~RES), J6.8, J12.2, RES1.1 (~RST), U3.3 (I3), U5.1, U5.2, VIA1.34 (~RES)
~WD: J6.5, J8.5, RAM1.29 (WE#), U2.5, U3.16 (IO4)
Ф2: ACIA1.27 (ϕ2), J6.6, U3.15 (IO5), VIA1.25 (ϕ2)

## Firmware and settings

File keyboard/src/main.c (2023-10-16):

/*
 * PS/2 keyboard implementation for ATmega328P
 * Supports multi-layer keymaps inspired by QMK firmware (https://qmk.fm/)
 * Keyboard is organized in 6x8 grid to save pins (versus 12x4 arrangement).
 * Matrix scanning order (diode direction) is row-to-column (rows are outputs, columns are inputs).
 * See ../../kicad/keyboard.kicad_sch for schematic
 */

#include <Arduino.h>

#include "scancodes.h"

#define COL_COUNT 6
#define ROW_COUNT 8
#define LAYERS    3

#define REPEAT_RATE       25
#define REPEAT_DELAY      200
#define DEBOUNCE_INTERVAL 10

#define PS2CLK  PIN_PD6
#define PS2DATA PIN_PD7

const uint8_t COLS[COL_COUNT] = {PIN_PB0, PIN_PB1, PIN_PB2, PIN_PB3, PIN_PB4, PIN_PB5};
const uint8_t ROWS[ROW_COUNT] = {PIN_PD0, PIN_PD1, PIN_PD2, PIN_PD3, PIN_PC4, PIN_PC3, PIN_PC2, PIN_PC1};
const uint16_t KEYMAP[LAYERS][COL_COUNT * ROW_COUNT] = {
    {
        // Layer 0
        //

        /* clang-format off */
        // Left half
        SC_TAB,   SC_Q,     SC_W,     SC_E,     SC_R,     SC_T,
        CC_LYR1,  SC_A,     SC_S,     SC_D,     SC_F,     SC_G,
        SC_LSHFT, SC_Z,     SC_X,     SC_C,     SC_V,     SC_B,
        SC_LCTRL, SC_ESC,   _____,    _____,    _____,    SC_SPACE,

        // Right half
        SC_Y,     SC_U,     SC_I,     SC_O,     SC_P,     SC_BKSPC,
        SC_H,     SC_J,     SC_K,     SC_L,     SC_SMCLN, SC_ENTER,
        SC_N,     SC_M,     SC_COMMA, SC_PRIOD, SC_SLASH, SC_LCTRL,
        SC_SPACE, CC_LYR2,  _____,    _____,    _____,    _____,
        /* clang-format on */
    },
    {
        // Layer 1
        //

        /* clang-format off */
        // Left half
        _____,    _____,    _____,    _____,    _____,    _____,
        _____,    _____,    _____,    _____,    _____,    _____,
        _____,    _____,    _____,    _____,    _____,    _____,
        _____,    _____,    _____,    _____,    _____,    _____,

        // Right half
        SC_MINUS, EC_PGUP,  EC_UP,    EC_PGDN,  _____,    EC_DEL,
        EC_HOME,  EC_LEFT,  EC_DOWN,  EC_RIGHT, SC_GRAVE, _____,
        EC_END,   SC_EQUAL, SC_LBRAC, SC_RBRAC, _____,    _____,
        _____,    _____,    _____,    _____,    _____,    _____,
        /* clang-format on */
    },
    {
        // Layer 2
        //

        /* clang-format off */
        // Left half
        _____,    SC_1,     SC_2,     SC_3,     SC_4,     SC_5,
        _____,    SC_F1,    SC_F2,    SC_F3,    SC_F4,    SC_F5,
        _____,    _____,    _____,    _____,    _____,    _____,
        _____,    _____,    _____,    _____,    _____,    _____,

        // Right half
        SC_6,     SC_7,     SC_8,     SC_9,     SC_0,     SC_F12,
        SC_F6,    SC_F7,    SC_F8,    SC_F9,    SC_F10,   SC_F11,
        _____,    _____,    _____,    _____,    _____,    _____,
        _____,    _____,    _____,    _____,    _____,    _____,
        /* clang-format on */
    },
};

#define INACTIVE 0xFF

// Defines which layer the key was pressed on and when.
typedef struct {
    // Layer on which the key was pressed, INACTIVE (0xFF) if not pressed.
    // We track this to properly break the key when it's released in case the layer has changed.
    uint8_t layer;
    // Is the key physically pressed at any point in time.
    // This is a raw value which is not debounced.
    // It's used to generate clean value for `layer` after debouncing.
    uint8_t phys;
    // When was the key pressed (for debouncing)
    uint32_t changedAt;
} key_state_t;

key_state_t keyStates[COL_COUNT * ROW_COUNT];
uint8_t currentLayer = 0;

// Last pressed key to repeat
uint16_t lastPressedKey = 0;
uint32_t nextRepeatAt = 0;

uint16_t handle_key(uint16_t keycode, bool isPressed);
void emit(uint16_t code, bool make);
void write(uint8_t code);
void writeBit(uint8_t bit);

// typedef struct {
//     uint8_t index;
//     uint16_t code;
//     uint32_t pressedAt;
// } pressed_key_info_t;

void setup() {
    pinMode(PS2CLK, OUTPUT);
    pinMode(PS2DATA, OUTPUT);
    digitalWrite(PS2CLK, HIGH);
    digitalWrite(PS2DATA, HIGH);
    for (uint8_t y = 0; y < ROW_COUNT; y++) {
        pinMode(ROWS[y], OUTPUT);
        digitalWrite(ROWS[y], HIGH);
    }
    for (uint8_t x = 0; x < COL_COUNT; x++) {
        pinMode(COLS[x], INPUT_PULLUP);
    }
    for (int i = 0; i < COL_COUNT * ROW_COUNT; i++) {
        keyStates[i].layer = INACTIVE;
        keyStates[i].phys = HIGH;
        keyStates[i].changedAt = 0;
    }

    // Send BAT
    delay(500);
    write(0xAA);
    delay(250);
}

// Scan the matrix
void loop() {
    if (lastPressedKey && millis() > nextRepeatAt) {
        emit(lastPressedKey, true);
        nextRepeatAt = millis() + 1000 / REPEAT_RATE;
    }

    for (uint8_t y = 0; y < ROW_COUNT; y++) {
        digitalWrite(ROWS[y], LOW);
        for (uint8_t x = 0; x < COL_COUNT; x++) {
            bool isPressed = digitalRead(COLS[x]) == LOW; // Key at (x;y) is pressed
            uint8_t index = y * COL_COUNT + x;
            key_state_t *keyState = &keyStates[index];
            bool wasPressed = keyState->phys;
            if (isPressed != wasPressed) {
                // Key state changed, start debouncing timer
                keyState->phys = isPressed;
                keyState->changedAt = millis();
            }

            // Check if debounce interval passed
            if (millis() - keyState->changedAt > DEBOUNCE_INTERVAL) {
                // Debounce interval passed
                bool wasActive = keyState->layer != INACTIVE;
                bool isActive = keyState->phys;
                if (isActive != wasActive) {
                    if (isActive) {
                        // Key pressed and is stable
                        keyState->layer = currentLayer;
                        lastPressedKey = handle_key(KEYMAP[currentLayer][index], true);
                        nextRepeatAt = millis() + REPEAT_DELAY;
                    } else {
                        // Key released and is stable
                        handle_key(KEYMAP[keyState->layer][index], false);
                        lastPressedKey = 0;
                        keyState->layer = INACTIVE;
                    }
                }
            }
        }
        digitalWrite(ROWS[y], HIGH);
    }
}

// Decide what to do when the key is pressed/released
uint16_t handle_key(uint16_t keycode, bool isPressed) {
    if (keycode == CC_LYR1) {
        currentLayer = isPressed ? 1 : 0;
        return 0;
    } else if (keycode == CC_LYR2) {
        currentLayer = isPressed ? 2 : 0;
        return 0;
    } else if (keycode) {
        emit(keycode, isPressed);
        return keycode;
    }
    return 0;
}

// Send PS/2 make/break sequence
void emit(uint16_t code, bool make) {
    if (!make) {
        write(0xF0);
    }
    if (code > 0xFF) {
        write((code >> 8) & 0xFF);
        code = code & 0xFF;
    }
    write(code);
}

// Write PS/2 packet
void write(uint8_t code) {
    writeBit(0); // Start bit
    uint8_t parity = 1;
    for (uint8_t i = 0; i < 8; i++) {
        // Data bits (LSB first)
        uint8_t bit = code & 0x01;
        writeBit(bit);
        parity += bit;
        code >>= 1;
    }
    writeBit(parity % 2);  // Parity bit
    writeBit(1);           // Stop bit
    delayMicroseconds(50); // Wait one entire clock cycle
}

// Write single bit with PS/2 clock cycle
void writeBit(uint8_t bit) {
    digitalWrite(PS2DATA, bit);
    delayMicroseconds(1);
    digitalWrite(PS2CLK, LOW);
    delayMicroseconds(25);
    digitalWrite(PS2CLK, HIGH);
    delayMicroseconds(25);
}

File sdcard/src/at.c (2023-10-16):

#include <stdio.h>
#include <conio.h>
#include <tgi.h>
#include <stdlib.h>
#include <string.h>

#include <api/system.h>
#include <api/uart.h>
#include <api/lcd.h>
#include <api/keyboard.h>
#include <api/wait.h>

#define SE 240
#define SB 250
#define WILL 251
#define WONT 252
#define DO 253
#define DONT 254
#define IAC 255

#define OPT_ECHO 1
#define OPT_SUPPRESS_GO_AHEAD 3
#define OPT_OUTPUT_LINE_WIDTH 8
#define OPT_OUTPUT_PAGE_SIZE 9
#define OPT_NEGOTIATE_ABOUT_WINDOW_SIZE 31

int main(int argc, char **argv);

struct flags_t {
    byte esc;
    byte echo;
    byte crlf;
    byte iac;
    byte cmd;
    byte escseq;
} flags;

char escseq_buf[64];
byte escseq_len;

/* byte buf[256]; */
/* byte bufsize; */

extern void uart_reset();

byte handle_esc_command(byte c) {
    if (c == 'q') {
        return 0;
    }
    if (c == 'e') {
        flags.echo = !flags.echo;
        if (flags.echo) {
            puts("Echo ON\n");
        } else {
            puts("Echo OFF\n");
        }
    }
    if (c == 'n') {
        flags.crlf = !flags.crlf;
        if (flags.crlf) {
            puts("CRLF on\n");
        } else {
            puts("CRLF off\n");
        }
    }
    if (c == 't') {
        puts("Sending telnet options\n");
        uart_write(IAC);
        wait1ms();
        wait1ms();
        uart_write(DO);
        wait1ms();
        wait1ms();
        uart_write(OPT_SUPPRESS_GO_AHEAD);
        wait1ms();
        wait1ms();

        uart_write(IAC);
        wait1ms();
        wait1ms();
        uart_write(WILL);
        wait1ms();
        wait1ms();
        uart_write(OPT_NEGOTIATE_ABOUT_WINDOW_SIZE);
        wait1ms();
        wait1ms();
    }
    if (c == 'd') {
        printhex(flags.esc);
        printhex(flags.echo);
        printhex(flags.crlf);
        printhex(flags.iac);
        printhex(flags.cmd);
    }
    if (c == 'c') {
        uart_write(3);
        wait1ms();
        wait1ms();
    }
    if (c == ']') {
        puts("Sending ESC\n");
        uart_write(0x1B);
        wait1ms();
        wait1ms();
    }
    flags.esc = 0;
    return 255;
}

void print(byte c) {
    /* printhex(c); */
    cputc(c);
}

int main(int argc, char **argv) {
    byte c;
    byte ret;
    byte x, y;
    char *token;

    flags.esc = 0;
    flags.echo = 1; // https://datatracker.ietf.org/doc/html/rfc857#section-3
    flags.crlf = 1;
    flags.iac = 0;
    flags.cmd = 0;
    flags.escseq = 0;

    while (1) {
        c = igetch();
        if (c == 0x1B) {
            // Enter/leave ESC mode
            flags.esc = !flags.esc;
            continue;
        }
        if (c) {
            if (flags.esc) {
                // ESC mode: Interpret user command
                ret = handle_esc_command(c);
                if (ret != 255) {
                    return ret;
                }
                continue;
            }

            if (flags.echo) {
                cputc(c);
            }
            if (c == 10 && flags.crlf) {
                uart_write(13);
                wait1ms();
                wait1ms();
                uart_write(10);
            } else {
                uart_write(c);
            }
        }
        if (uart_has_data()) {
            c = uart_get();
            if (flags.iac) {
                // Previous byte was IAC
                flags.iac = 0;
                if (c == IAC) {
                    // Got duplicate IAC, pass transparently
                    print(IAC);
                    continue;
                }
                if (c == SB) {
                    // Subnegotiation start
                    // puts("< SB ");
                    // printhex(c);
                    // cputc('\n');
                    flags.cmd = c;
                    continue;
                }
                if (c == SE) {
                    // Subnegotiation end
                    // puts("< SE\n");
                    flags.cmd = 0;
                    continue;
                }
                if (c >= WILL && c <= DONT) {
                    // puts("< WWDD\n");
                    // General command
                    flags.cmd = c;
                    continue;
                }
            }
            if (flags.cmd) {
                // In command
                if (flags.cmd >= WILL && flags.cmd <= DONT) {
                    byte *s;
                    if (flags.cmd == WILL) {
                        s = (byte *)"WILL";
                    }
                    if (flags.cmd == WONT) {
                        s = (byte *)"WONT";
                    }
                    if (flags.cmd == DO) {
                        s = (byte *)"DO";
                    }
                    if (flags.cmd == DONT) {
                        s = (byte *)"DONT";
                    }
                    // puts("< ");
                    // puts(s);
                    // cputc(' ');
                    // printhex(c);
                    // cputc('\n');
                    if (flags.cmd == DO && c == OPT_NEGOTIATE_ABOUT_WINDOW_SIZE) {
                        // Send NAWS (40xLCD_ROWS display)
                        uart_write(IAC);
                        wait1ms();
                        wait1ms();
                        uart_write(SB);
                        wait1ms();
                        wait1ms();
                        uart_write(OPT_NEGOTIATE_ABOUT_WINDOW_SIZE);
                        wait1ms();
                        wait1ms();
                        uart_write(0);
                        wait1ms();
                        wait1ms();
                        uart_write(tgi_getmaxx() + 1);
                        wait1ms();
                        wait1ms();
                        uart_write(0);
                        wait1ms();
                        wait1ms();
                        uart_write(tgi_getmaxy() + 1);
                        wait1ms();
                        wait1ms();
                        uart_write(IAC);
                        wait1ms();
                        wait1ms();
                        uart_write(SE);
                    }
                    if ((flags.cmd == WILL || flags.cmd == WONT) && c == OPT_ECHO) {
                        flags.echo = flags.cmd == WONT;
                        uart_write(IAC);
                        wait1ms();
                        wait1ms();
                        uart_write(flags.cmd == WILL ? DO : DONT);
                        wait1ms();
                        wait1ms();
                        uart_write(OPT_ECHO);
                        wait1ms();
                        wait1ms();
                    }
                    flags.cmd = 0;
                }
                continue;
            }
            // Standard data
            if (c == IAC) {
                // Received IAC
                // puts("< IAC\n");
                flags.iac = 1;
                continue;
            }
            if (c == 0x1B) {
                // Received ESC
                // puts("< ESC\n");
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

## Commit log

2023-02-19 Add address lines to 74HC138 (I/O address decoder)
    [main.kicad_sch]
2023-02-24 Final PCB layout (<10*10 cm)
    [main.kicad_pcb, main.kicad_sch]
2023-02-24 Add diptrace PCB
    [main.kicad_pcb]
2023-02-24 Add Digital circuits & update README
    [main.kicad_pcb]
2023-02-24 Add LEDs
    [main.kicad_pcb, main.kicad_sch]
2023-02-25 Add memory map to README, update diptrace PCB
2023-02-25 Add 3D model for ZIF socket - thanks Stefany Allaire: https://grabcad.com/library/28pins-zif-socket-placeholder-1
    [28ZIF_PlaceHolderRevB.stp, main.kicad_pcb]
2023-02-25 Add 3D precision sockets
    [main.kicad_pcb]
2023-02-25 Update V8 schematics, move I/O to $Dxxx
    [main.kicad_pcb, main.kicad_sch]
2023-02-26 V9 & GAL stuff
    [main.kicad_pcb, main.kicad_sch]
2023-02-27 Add standoffs, update V9 render
    [DIN 934 Nut M3.STEP, Hex Spacer MF M3 L10mm.stp, main.kicad_pcb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]
2023-02-27 Add Traco Power TSR 1-2450
    [TSR_1-2450.step, main.kicad_pcb, main.kicad_sch]
2023-02-28 Update ROM code to be runnable in sim65, increase PCB spacing at borders
    [main.kicad_pcb, main.kicad_sch, rom.cfg]
2023-02-28 Update PCB wording, remove outer rectangle
    [Board.gbr, Bot.gbr, BotMask.gbr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]
2023-03-08 Cleanup segment names
    [rom.cfg]
2023-03-09 Add number printing operations (hex & binary repr)
2023-03-09 Add VIA free-running timer interrupts
2023-03-10 Add vdelay
    [rom.cfg]
2023-03-12 V0.12: (PS/2 & 4-bit LCD with VIA), cleanup kicad libs
    [28ZIF_PlaceHolderRevB.stp, DIN_934_Nut_M3.stp, Hex_Spacer_MF_M3_L10mm.stp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]
2023-03-12 Update README & images
    [main.kicad_pcb, main.kicad_sch]
2023-03-12 Add repl module, printmem command, lowercase hex parsing
2023-03-12 Make jumptable cleaner, improve hex character parsing
    [rom.cfg]
2023-03-14 Cleanup code, add docstrings
    [rom.cfg]
2023-03-15 Implement running programs from FAT16 SD card, add sample program
2023-03-16 Test illegal opcodes, update SPI pin assignments, update V12 PCB
    [main.kicad_pcb, main.kicad_sch]
2023-03-17 Refactor ROM code to use carry flag for errors.Add Aries low-profile ZIF socket to V12 board.
    [main.kicad_pcb, main.kicad_sch]
2023-03-18 Add lcd::printfz function. Cleanup macros.
    [main.kicad_pcb]
2023-03-18 Add ATtiny45 assembly scaffold
2023-03-19 Update ATtiny PAL rendering timings
    [main.kicad_sch]
2023-03-25 V13 - 32K RAM + 24K ROM
    [main.kicad_pcb, main.kicad_sch, rom.cfg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]
2023-03-28 WIP: v0.14
    [main.kicad_pcb, main.kicad_sch]
2023-04-05 WIP: v0.15
    [Board.gbr, Bot.gbr, BotAssembly.gbr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]
2023-04-09 Fix PS/2 desync due to long SEI init
    [rom.cfg]
2023-04-09 Fix resistor values
    [main.kicad_sch]
2023-04-09 Add ctest
    [rom.cfg]
2023-04-10 Dual support for ASM & C programs. Took some time!
    [keyboard.kicad_pcb, keyboard.kicad_sch, rom.cfg]
2023-04-11 Load large files from FAT16, WIP for Maze
    [keyboard.kicad_pcb, keyboard.kicad_sch]
2023-04-13 V15 assembly images
    [main.kicad_sch, rom.cfg]
2023-05-07 Implement I2C driver, add DS1307N RTC clock control program
2023-05-07 Attempt at modules and stuff
    [rom.cfg]
2023-05-07 Proper Kernel API for mixed C & ASM applications!
    [rom.cfg]
2023-05-07 Rewrite main process in C
    [rom.cfg]
2023-05-07 Add "system" and "exec"
    [rom.cfg]
2023-05-07 Add directory listing & I2C scanner
2023-05-07 Add I2C routines for more efficient register read/write operations
2023-05-07 Add RTC & CR2032 battery, increase size of decoupling capacitors
    [main.kicad_pcb, main.kicad_sch]
2023-05-08 WIP: V16
    [main.kicad_pcb, main.kicad_sch]
2023-05-09 WIP: V16 GAL stuff
    [Board.gbr, Bot.gbr, BotAssembly.gbr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]
2023-05-09 Replace address decoder & r/w qualifier with GAL
    [main.kicad_pcb, main.kicad_sch]
2023-05-10 Replace GAL20V8 with GAL(ATF)16V8
    [Board.gbr, Bot.gbr, BotAssembly.gbr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]
2023-05-10 Move power socket to top, move GAL down a bit
    [Board.gbr, Bot.gbr, BotAssembly.gbr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]
2023-05-11 Generate top silk layer with Kicad
    [main.kicad_pcb, main.kicad_sch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]
2023-05-12 Route /RST to ESP-01
    [Board.gbr, Bot.gbr, BotAssembly.gbr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]
2023-05-15 Update silkscreen
    [main.kicad_pcb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]
2023-05-20 V16 with working display
    [main.kicad_sch]
2023-05-25 WIP: UART
2023-07-22 v18: RAM banking, clock through inverters
    [1 - Top.gbr, 2 - Bottom.gbr, Board.gbr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]
2023-07-26 WIP: v2.0 initial PCB
    [expansion.kicad_sch, keyboard.kicad_pcb, keyboard.kicad_sch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]
2023-07-27 WIP: v2.0 split board
    [keyboard.kicad_sch, main.kicad_pcb, main.kicad_sch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]
2023-07-28 v2.0: Final PCB
    [1 - Top.gbr, 2 - Bottom.gbr, Board.gbr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]
2023-07-28 WIP: v2.0 case
    [main-Board.gbr, main-F_Fab.gbr, main-job.gbrjob]
2023-07-30 Update case
    [top_test.dxf]
2023-08-02 Cleanup case files
    [top_test.dxf]
2023-08-07 Fix keyboard scanning code
    [main.c]
2023-08-20 v2.1 PCB
    [main.kicad_pcb, main.kicad_sch]
2023-08-27 Add missing keys to keyboard
    [main.c]
2023-08-27 v2.1 updates
    [1 - Top.gbr, 2 - Bottom.gbr, BoardOutline.gbr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]
2023-09-13 Fix time app, fix at app telnet commands (needed passthrough in WiFiModem), fix exec return codes
    [at.c, time.c]
2023-09-14 Add missing \t char to PS/2 driver
2023-09-14 Add KLS7 switch, remove buttons from top panel
    [bottom.dxf, bottom_print.dxf, top.dxf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]
2023-09-17 Add FreeCAD project, add v2.0 renders, add Kailh Choc 3D model
    [Kailh Choc Low Profile Switch.step, bottom_print.dxf, main.kicad_pcb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]
2023-09-18 Update case files
    [bottom.dxf, bottom_print.dxf, middle.dxf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]
2023-09-20 Fix wrong LCD width in case files, add LCD model
    [lcd.FCStd, main_case.FCStd, top.dxf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]
2023-09-25 Fix symbols & LCD footprint
    [lcd.FCStd]
2023-10-03 Case images
2023-10-03 Add case images
2023-11-28 SPI circuit
